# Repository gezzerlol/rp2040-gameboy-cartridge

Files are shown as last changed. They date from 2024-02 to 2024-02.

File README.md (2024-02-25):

2 layer pcb version of Shilga's RP2040 Gameboy flash cartridge. Also replaced some components with bigger packages, and easier to find components.

Changes:
-Removed inner layers, instead routed buses and tracks in place of the power planes at the back layer. Also one single signal track is moved to the back layer.
-Replaced 1005 caps with 1608's. JLCPCB doesn't do 1005 package in ecomomic PCBA service.
-Added an optional location for AMS1117-3.3 regulator, in case the MCP1825T isn't available. If AMS1117-3.3 is used, JP2 middle pad solder mask should be removed and soldered to supply a constant POWERGOOD signal that enables the level shifters. 

With these three changes, the PCB could be manufactured at 2$ for 5pcs at JLCPCB. Also if PCBA service is needed, it reduces the number of the extended components that add 3$ of setup fee each. 

The RP2040, TXB0108, TXB0102 and the WS2812b are inevitably extended parts at JLCPCB.

Not tested:
-The whole PCB
-JP2 POWERGOOD bypass functionality(keeping IC's enabled at all times may be a problem)
-Replacement of power planes with tracks
-AMS1117-3.3 compatibility

Goals:
-Replacement of TXB level shifters with discrete circuits made of jellybean transistors. This might be difficult because there are 26 data lines that needs to be level shifted and there is little space, too much moving around might be needed. Heck, might even need to use the back layer.
-Replacement of CJ2302 mosfet with a cheaper one. AO3400A might be a candidate.
-Replacement of the diodes with jellybean ones
-Making the whole pcb made of jellybean parts except RP2040

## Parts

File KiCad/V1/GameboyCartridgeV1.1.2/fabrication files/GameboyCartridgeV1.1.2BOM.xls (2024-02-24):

Designator | Footprint | Quantity | Comment | JLCPCB Part #（optional）
J1 | USB_C_Receptacle_GCT_USB4105-xx-A_16P_TopMnt_Horizontal | 1 | USB_C_Receptacle_USB2.0
C8,C18,C12,C2,C13,C5,C21,C20,C17,C23,C6,C19,C9,C24,C10,C14,C1,C22 | C_0603_1608Metric_Pad1.08x0.95mm_HandSolder | 18 | 100nF
JP2 | SolderJumper-3_P1.3mm_Open_RoundedPad1.0x1.5mm_NumberLabels | 1 | SolderJumper_3_Open
R3,R2 | R_0603_1608Metric_Pad0.98x0.95mm_HandSolder | 2 | 27R
R4,R8 | R_0603_1608Metric_Pad0.98x0.95mm_HandSolder | 2 | 1k
U9 | SOT-223-3_TabPin2 | 1 | AMS1117-3.3
SW1 | SW_SPST_TL3342 | 1 | SW_Push
R9,R7 | R_0603_1608Metric_Pad0.98x0.95mm_HandSolder | 2 | 470k
U4 | SOT230P700X180-6N | 1 | MCP1825T-3302E/DC
C3,C4 | C_0603_1608Metric_Pad1.08x0.95mm_HandSolder | 2 | 15pF
U2 | QFN-56-1EP_7x7mm_P0.4mm_EP3.2x3.2mm | 1 | RP2040
Y1 | Crystal_SMD_TXC_7M-4Pin_3.2x2.5mm | 1 | 12MHz
R5 | R_0603_1608Metric_Pad0.98x0.95mm_HandSolder | 1 | 10R
D1 | LED_WS2812B_PLCC4_5.0x5.0mm_P3.2mm | 1 | WS2812B
U8,U7,U6 | TSSOP-20_4.4x6.5mm_P0.65mm | 3 | TXB0108PW
C16 | C_0603_1608Metric_Pad1.08x0.95mm_HandSolder | 1 | 10uF
U1 | SOIC-8_5.23x5.23mm_P1.27mm | 1 | W25Q128JVS
R6,R1 | R_0603_1608Metric_Pad0.98x0.95mm_HandSolder | 2 | 10k
D3,D2 | D_SOD-123F | 2 | D_Schottky
C15 | C_0603_1608Metric_Pad1.08x0.95mm_HandSolder | 1 | 4.7uF
Q1 | SOT-23_Handsoldering | 1 | CJ2302
U5 | VSSOP-8_2.4x2.1mm_P0.5mm | 1 | TXB0102DCU
C11,C7 | C_0603_1608Metric_Pad1.08x0.95mm_HandSolder | 2 | 2.2uF

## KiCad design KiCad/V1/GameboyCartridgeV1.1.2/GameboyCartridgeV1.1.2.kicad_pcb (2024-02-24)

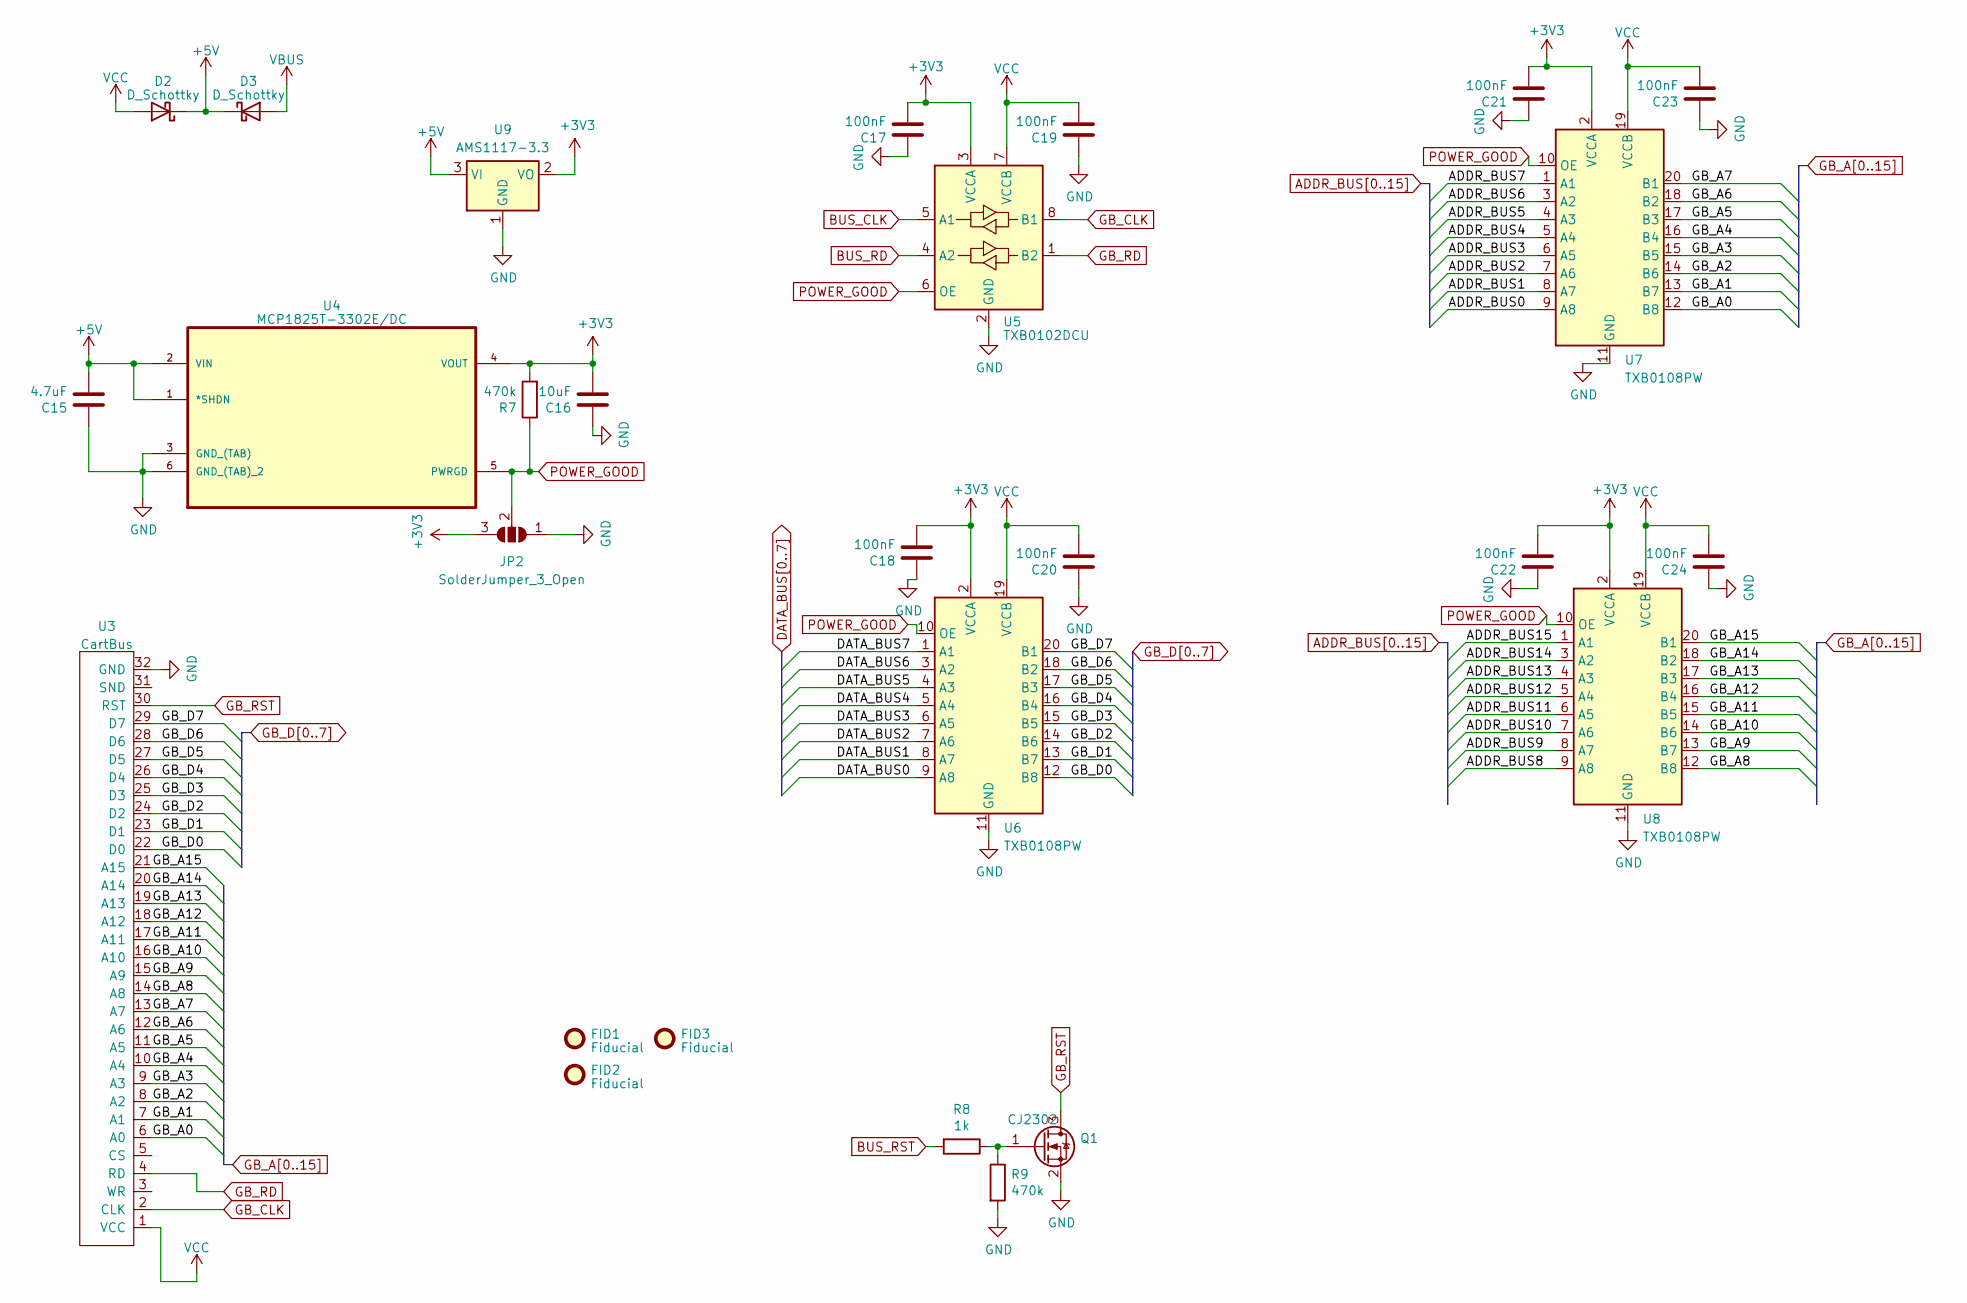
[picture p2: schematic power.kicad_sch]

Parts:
C15: 4.7uF; C_0603_1608Metric_Pad1.08x0.95mm_HandSolder
C16: 10uF; C_0603_1608Metric_Pad1.08x0.95mm_HandSolder
C17, C18, C19, C20, C21, C22, C23, C24: 100nF; C_0603_1608Metric_Pad1.08x0.95mm_HandSolder
D2, D3: D_Schottky; D_SOD-123F; LCSC C669022
FID1, FID2, FID3: Fiducial; Fiducial_1mm_Mask2mm
JP2: SolderJumper_3_Open; SolderJumper-3_P1.3mm_Open_RoundedPad1.0x1.5mm_NumberLabels
Q1: CJ2302; SOT-23_Handsoldering; LCSC C8548
R7, R9: 470k; R_0603_1608Metric_Pad0.98x0.95mm_HandSolder
R8: 1k; R_0603_1608Metric_Pad0.98x0.95mm_HandSolder
U3: CartBus; GameBoy_Cartridge_EdgeConnector
U4: MCP1825T-3302E/DC; SOT230P700X180-6N; MPN MCP1825T-3302E/DC; LCSC C632684
U5: TXB0102DCU; VSSOP-8_2.4x2.1mm_P0.5mm; LCSC C60709
U6, U7, U8: TXB0108PW; TSSOP-20_4.4x6.5mm_P0.65mm; LCSC C53406
U9: AMS1117-3.3; SOT-223-3_TabPin2

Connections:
+3V3: C16.2, C17.2, C18.2, C21.2, C22.2, JP2.3 (B), R7.2, U4.4 (VOUT), U5.3 (VCCA), U6.2 (VCCA), U7.2 (VCCA), U8.2 (VCCA), U9.2 (VO); also elsewhere on the board
+5V: C15.2, D2.1 (K), D3.1 (K), U4.1 (*SHDN), U4.2 (VIN), U9.3 (VI)
ADDR_BUS0: U7.9 (A8); also elsewhere on the board
ADDR_BUS1: U7.8 (A7); also elsewhere on the board
ADDR_BUS2: U7.7 (A6); also elsewhere on the board
ADDR_BUS3: U7.6 (A5); also elsewhere on the board
ADDR_BUS4: U7.5 (A4); also elsewhere on the board
ADDR_BUS5: U7.4 (A3); also elsewhere on the board
ADDR_BUS6: U7.3 (A2); also elsewhere on the board
ADDR_BUS7: U7.1 (A1); also elsewhere on the board
ADDR_BUS8: U8.9 (A8); also elsewhere on the board
ADDR_BUS9: U8.8 (A7); also elsewhere on the board
ADDR_BUS10: U8.7 (A6); also elsewhere on the board
ADDR_BUS11: U8.6 (A5); also elsewhere on the board
ADDR_BUS12: U8.5 (A4); also elsewhere on the board
ADDR_BUS13: U8.4 (A3); also elsewhere on the board
ADDR_BUS14: U8.3 (A2); also elsewhere on the board
ADDR_BUS15: U8.1 (A1); also elsewhere on the board
BUS_CLK: U5.5 (A1); also elsewhere on the board
BUS_RD: U5.4 (A2); also elsewhere on the board
BUS_RST: R8.2; also elsewhere on the board
DATA_BUS0: U6.9 (A8); also elsewhere on the board
DATA_BUS1: U6.8 (A7); also elsewhere on the board
DATA_BUS2: U6.7 (A6); also elsewhere on the board
DATA_BUS3: U6.6 (A5); also elsewhere on the board
DATA_BUS4: U6.5 (A4); also elsewhere on the board
DATA_BUS5: U6.4 (A3); also elsewhere on the board
DATA_BUS6: U6.3 (A2); also elsewhere on the board
DATA_BUS7: U6.1 (A1); also elsewhere on the board
GB_A0: U3.6 (A0), U7.12 (B8)
GB_A1: U3.7 (A1), U7.13 (B7)
GB_A2: U3.8 (A2), U7.14 (B6)
GB_A3: U3.9 (A3), U7.15 (B5)
GB_A4: U3.10 (A4), U7.16 (B4)
GB_A5: U3.11 (A5), U7.17 (B3)
GB_A6: U3.12 (A6), U7.18 (B2)
GB_A7: U3.13 (A7), U7.20 (B1)
GB_A8: U3.14 (A8), U8.12 (B8)
GB_A9: U3.15 (A9), U8.13 (B7)
GB_A10: U3.16 (A10), U8.14 (B6)
GB_A11: U3.17 (A11), U8.15 (B5)
GB_A12: U3.18 (A12), U8.16 (B4)
GB_A13: U3.19 (A13), U8.17 (B3)
GB_A14: U3.20 (A14), U8.18 (B2)
GB_A15: U3.21 (A15), U8.20 (B1)
GB_CLK: U3.2 (CLK~), U5.8 (B1)
GB_D0: U3.22 (D0), U6.12 (B8)
GB_D1: U3.23 (D1), U6.13 (B7)
GB_D2: U3.24 (D2), U6.14 (B6)
GB_D3: U3.25 (D3), U6.15 (B5)
GB_D4: U3.26 (D4), U6.16 (B4)
GB_D5: U3.27 (D5), U6.17 (B3)
GB_D6: U3.28 (D6), U6.18 (B2)
GB_D7: U3.29 (D7), U6.20 (B1)
GB_RD: U3.4 (RD), U5.1 (B2)
GB_RST: Q1.3 (D), U3.30 (RST)
GND: C15.1, C16.1, C17.1, C18.1, C19.1, C20.1, C21.1, C22.1, C23.1, C24.1, JP2.1 (A), Q1.2 (S), R9.2, U3.32 (GND), U4.3 (GND_(TAB)), U4.6 (GND_(TAB)_2), U5.2 (GND), U6.11 (GND), U7.11 (GND), U8.11 (GND), U9.1 (GND); also elsewhere on the board
unnamed: Q1.1 (G), R8.1, R9.1
POWER_GOOD: JP2.2 (C), R7.1, U4.5 (PWRGD), U5.6 (OE), U6.10 (OE), U7.10 (OE), U8.10 (OE)
VBUS: D3.2 (A); also elsewhere on the board
VCC: C19.2, C20.2, C23.2, C24.2, D2.2 (A), U3.1 (VCC), U5.7 (VCCB), U6.19 (VCCB), U7.19 (VCCB), U8.19 (VCCB)

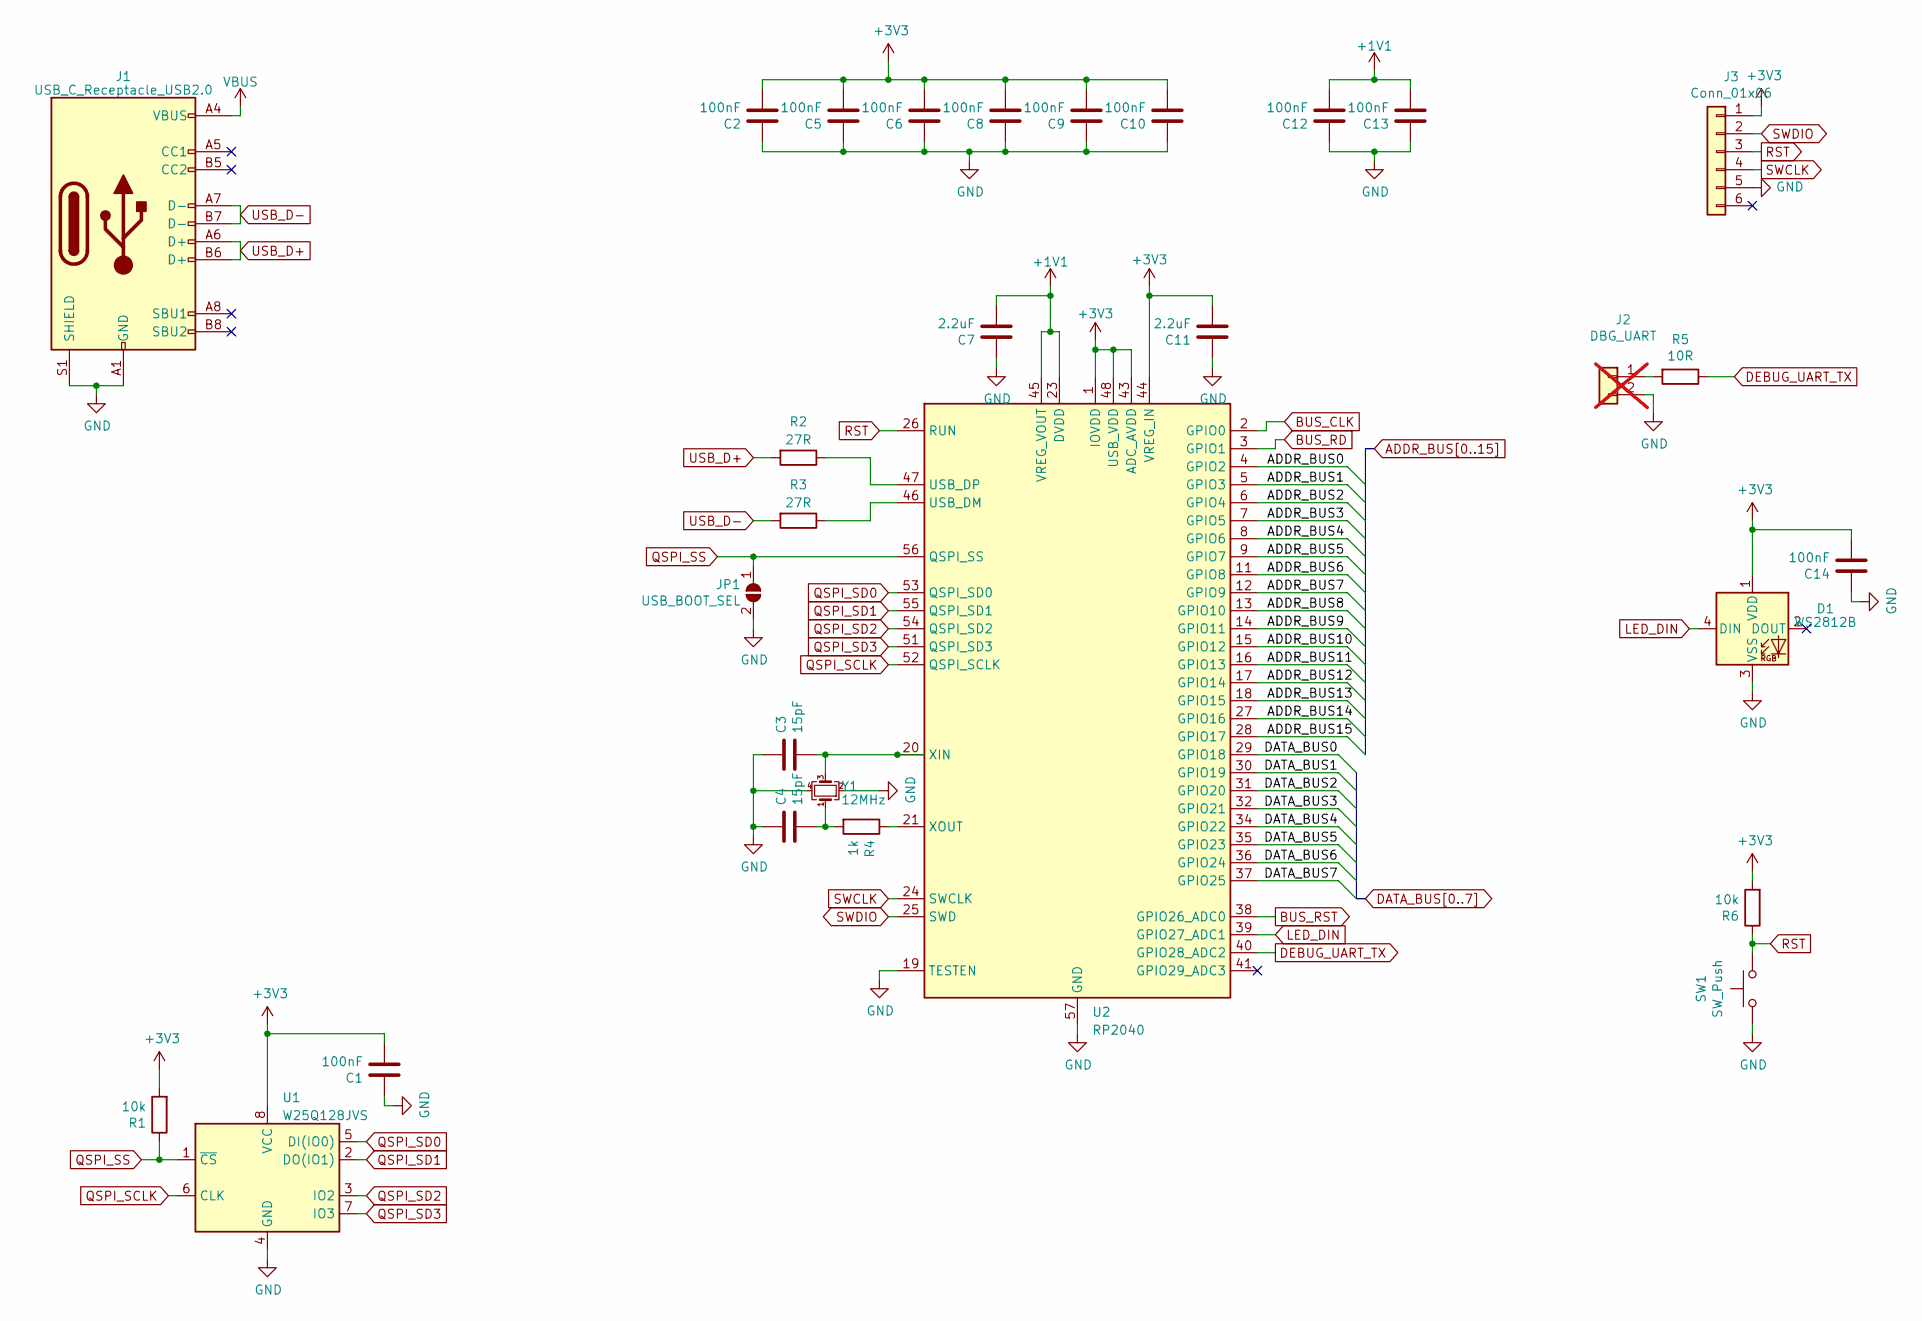
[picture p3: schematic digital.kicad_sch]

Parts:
C1, C2, C5, C6, C8, C9, C10, C12, C13, C14: 100nF; C_0603_1608Metric_Pad1.08x0.95mm_HandSolder
C3, C4: 15pF; C_0603_1608Metric_Pad1.08x0.95mm_HandSolder; LCSC C1644
C7, C11: 2.2uF; C_0603_1608Metric_Pad1.08x0.95mm_HandSolder
D1: WS2812B; LED_WS2812B_PLCC4_5.0x5.0mm_P3.2mm; LCSC C2761795
J1: USB_C_Receptacle_USB2.0; USB_C_Receptacle_GCT_USB4105-xx-A_16P_TopMnt_Horizontal; LCSC C2927037
J2: DBG_UART; PinHeader_1x02_P2.54mm_Horizontal; not fitted
J3: Conn_01x06; Tag-Connect_TC2030-IDC-FP_2x03_P1.27mm_Vertical
JP1: USB_BOOT_SEL; SolderJumper-2_P1.3mm_Open_RoundedPad1.0x1.5mm
R1, R6: 10k; R_0603_1608Metric_Pad0.98x0.95mm_HandSolder
R2, R3: 27R; R_0603_1608Metric_Pad0.98x0.95mm_HandSolder
R4: 1k; R_0603_1608Metric_Pad0.98x0.95mm_HandSolder
R5: 10R; R_0603_1608Metric_Pad0.98x0.95mm_HandSolder
SW1: SW_Push; SW_SPST_TL3342; LCSC C2886898
U1: W25Q128JVS; SOIC-8_5.23x5.23mm_P1.27mm; LCSC C97521
U2: RP2040; QFN-56-1EP_7x7mm_P0.4mm_EP3.2x3.2mm; LCSC C2040
Y1: 12MHz; Crystal_SMD_TXC_7M-4Pin_3.2x2.5mm; LCSC C668845

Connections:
+1V1: C7.2, C12.2, C13.2, U2.23 (DVDD), U2.45 (VREG_VOUT), U2.50 (DVDD)
+3V3: C1.2, C2.2, C5.2, C6.2, C8.2, C9.2, C10.2, C11.2, C14.2, D1.1 (VDD), J3.1, R1.2, R6.2, U1.8 (VCC), U2.1 (IOVDD), U2.10 (IOVDD), U2.22 (IOVDD), U2.33 (IOVDD), U2.42 (IOVDD), U2.43 (ADC_AVDD), U2.44 (VREG_IN), U2.48 (USB_VDD), U2.49 (IOVDD); also elsewhere on the board
ADDR_BUS0: U2.4 (GPIO2); also elsewhere on the board
ADDR_BUS1: U2.5 (GPIO3); also elsewhere on the board
ADDR_BUS2: U2.6 (GPIO4); also elsewhere on the board
ADDR_BUS3: U2.7 (GPIO5); also elsewhere on the board
ADDR_BUS4: U2.8 (GPIO6); also elsewhere on the board
ADDR_BUS5: U2.9 (GPIO7); also elsewhere on the board
ADDR_BUS6: U2.11 (GPIO8); also elsewhere on the board
ADDR_BUS7: U2.12 (GPIO9); also elsewhere on the board
ADDR_BUS8: U2.13 (GPIO10); also elsewhere on the board
ADDR_BUS9: U2.14 (GPIO11); also elsewhere on the board
ADDR_BUS10: U2.15 (GPIO12); also elsewhere on the board
ADDR_BUS11: U2.16 (GPIO13); also elsewhere on the board
ADDR_BUS12: U2.17 (GPIO14); also elsewhere on the board
ADDR_BUS13: U2.18 (GPIO15); also elsewhere on the board
ADDR_BUS14: U2.27 (GPIO16); also elsewhere on the board
ADDR_BUS15: U2.28 (GPIO17); also elsewhere on the board
BUS_CLK: U2.2 (GPIO0); also elsewhere on the board
BUS_RD: U2.3 (GPIO1); also elsewhere on the board
BUS_RST: U2.38 (GPIO26_ADC0); also elsewhere on the board
DATA_BUS0: U2.29 (GPIO18); also elsewhere on the board
DATA_BUS1: U2.30 (GPIO19); also elsewhere on the board
DATA_BUS2: U2.31 (GPIO20); also elsewhere on the board
DATA_BUS3: U2.32 (GPIO21); also elsewhere on the board
DATA_BUS4: U2.34 (GPIO22); also elsewhere on the board
DATA_BUS5: U2.35 (GPIO23); also elsewhere on the board
DATA_BUS6: U2.36 (GPIO24); also elsewhere on the board
DATA_BUS7: U2.37 (GPIO25); also elsewhere on the board
DEBUG_UART_TX: R5.1, U2.40 (GPIO28_ADC2)
GND: C1.1, C2.1, C3.1, C4.1, C5.1, C6.1, C7.1, C8.1, C9.1, C10.1, C11.1, C12.1, C13.1, C14.1, D1.3 (VSS), J1.A1 (GND), J1.A12 (GND), J1.B1 (GND), J1.B12 (GND), J1.S1 (SHIELD), J2.2, J3.5, JP1.2 (B), SW1.2, U1.4 (GND), U2.19 (TESTEN), U2.57 (GND), Y1.2, Y1.4; also elsewhere on the board
LED_DIN: D1.4 (DIN), U2.39 (GPIO27_ADC1)
unnamed: C4.2, R4.2, Y1.1
unnamed: J2.1, R5.2
unnamed: R3.1, U2.46 (USB_DM)
unnamed: R2.1, U2.47 (USB_DP)
unnamed: C3.2, U2.20 (XIN), Y1.3
unnamed: R4.1, U2.21 (XOUT)
QSPI_SCLK: U1.6 (CLK), U2.52 (QSPI_SCLK)
QSPI_SD0: U1.5 (DI(IO0)), U2.53 (QSPI_SD0)
QSPI_SD1: U1.2 (DO(IO1)), U2.55 (QSPI_SD1)
QSPI_SD2: U1.3 (IO2), U2.54 (QSPI_SD2)
QSPI_SD3: U1.7 (IO3), U2.51 (QSPI_SD3)
QSPI_SS: JP1.1 (A), R1.1, U1.1 (~CS), U2.56 (QSPI_SS)
RST: J3.3, R6.1, SW1.1, U2.26 (RUN)
SWCLK: J3.4, U2.24 (SWCLK)
SWDIO: J3.2, U2.25 (SWD)
USB_D+: J1.A6 (D+), J1.B6 (D+), R2.2
USB_D-: J1.A7 (D-), J1.B7 (D-), R3.2
VBUS: J1.A4 (VBUS), J1.A9 (VBUS), J1.B4 (VBUS), J1.B9 (VBUS); also elsewhere on the board

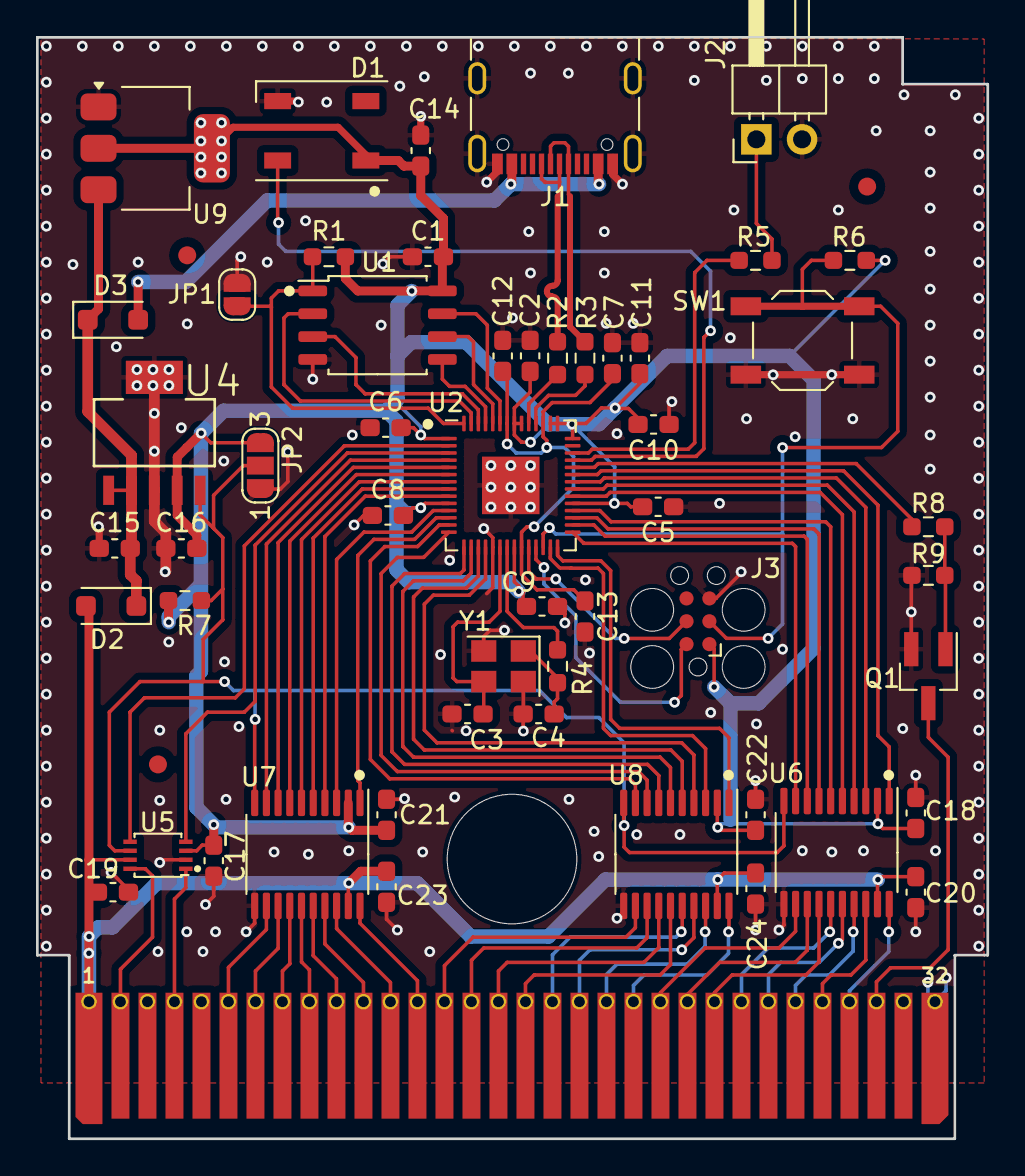
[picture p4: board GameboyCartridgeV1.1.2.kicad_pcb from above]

Board: 2 copper layers, 52.8 x 61.2 mm, 56 parts (0 on the bottom side), 81 nets.
